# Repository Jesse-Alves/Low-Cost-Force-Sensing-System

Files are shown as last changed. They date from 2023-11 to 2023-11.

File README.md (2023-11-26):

<!-- Improved compatibility of back to top link: See: https://github.com/othneildrew/Best-README-Template/pull/73 -->

<!--
*** Thanks for checking out the Best-README-Template. If you have a suggestion
*** that would make this better, please fork the repo and create a pull request
*** or simply open an issue with the tag "enhancement".
*** Don't forget to give the project a star!
*** Thanks again! Now go create something AMAZING! :D
-->

<!-- PROJECT SHIELDS -->
<!--
*** I'm using markdown "reference style" links for readability.
*** Reference links are enclosed in brackets [ ] instead of parentheses ( ).
*** See the bottom of this document for the declaration of the reference variables
*** for contributors-url, forks-url, etc. This is an optional, concise syntax you may use.
*** https://www.markdownguide.org/basic-syntax/#reference-style-links
-->
[][linkedin-url]

<!-- PROJECT LOGO -->
<br />
<div align="center">
  <a href="https://healthtech.unistra.fr/">
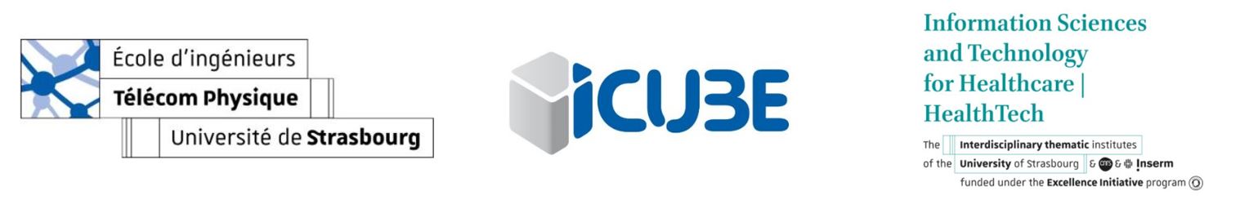
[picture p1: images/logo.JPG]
    
  </a>

  <h1 align="center">Low-Cost Force Sensing System Prototyping for Upper-Limb Rehabilitation</h1>

  <p align="center">
    <a href="https://github.com/Jesse-Alves?tab=repositories"><strong>View all repositories  »</strong></a>
    <br />
    <br />
  </p>
</div>

<!-- TABLE OF CONTENTS -->
<details>
  <summary>Table of Contents</summary>
  <ol>
    <li>
      <a href="#about-the-project">About The Project</a>
      <ul>
        <li><a href="#built-with">Built With</a></li>
      </ul>
    </li>
    <li>
      <a href="#getting-started">Getting Started</a>
      <ul>
        <li><a href="#prerequisites">Prerequisites</a></li>
<!--         <li><a href="#installation">Installation</a></li> -->
      </ul>
    </li>
    <li><a href="#usage">Usage</a></li>
<!--     <li><a href="#roadmap">Roadmap</a></li>
    <li><a href="#contributing">Contributing</a></li>
    <li><a href="#license">License</a></li> -->
    <li><a href="#contact">Contact</a></li>
<!--     <li><a href="#acknowledgments">Acknowledgments</a></li> -->
  </ol>
</details>

<!-- ABOUT THE PROJECT -->
## About The Project

Currently, robotics-assisted devices, such as exoskeleton and collaborative robotic arms, have been used for rehabilitation therapy. Where one of the biggest causes of the physical disability is stroke. However, despite the high benefits and potential of using these devices, the clinical application remains limited due mainly to the complexity and the high cost. Therefore, different strategies are used to overcome these limitations, such as the use of alternatives sensors and materials. In this context, this article presents the prototyping of a low cost and compact bracelet to detect the upper arm contraction using Force Sensing Resistor (FSR) and then, send the data from a cheap microcontroller to Robot Operating System (ROS2) environment.

Keywords: Rehabilitation, Post-Stroke, Robotic, FSR, Low-Cost.

[(Full article)](https://github.com/Jesse-Alves/Low-Cost-Force-Sensing-System-Prototyping-for-Upper-Limb-Rehabilitation/blob/main/Low-Cost%20Force%20Sensing%20System%20Prototyping%20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)

## Experiment with prototype

<div align="center">
    color picker
</div>

[(Full Test Video)](https://1drv.ms/v/s!Ah6ATMOdK-3mgutUfqPUrB_IlDdTVw?e=WdsoXN)

### Prototype Pictures

<div align="center">
  <a href=" ">
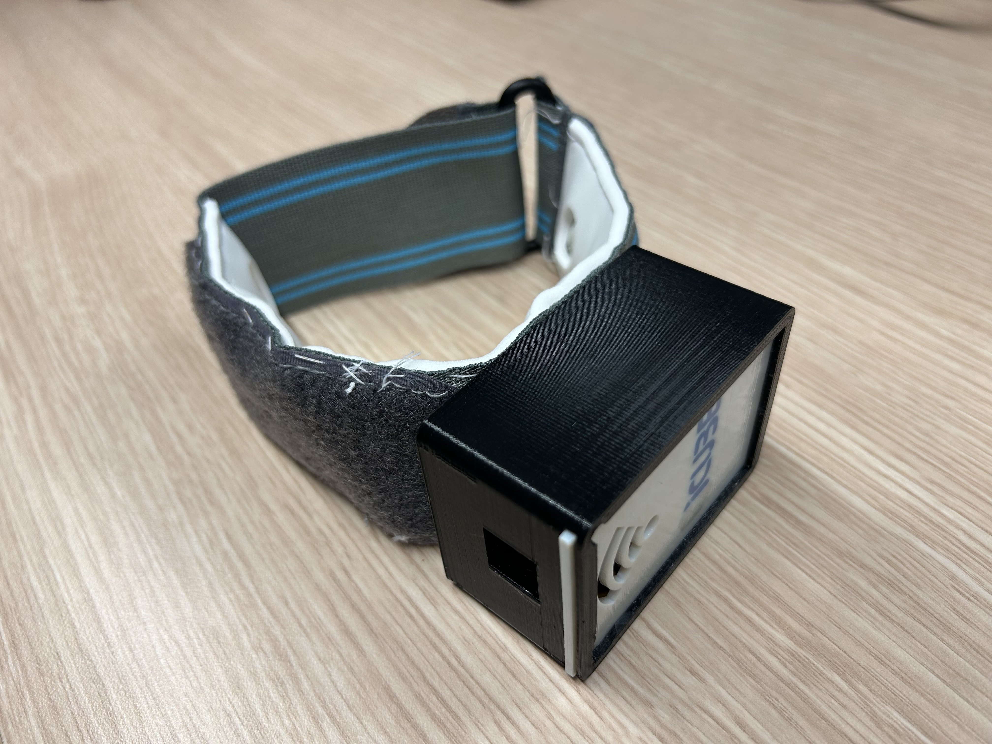
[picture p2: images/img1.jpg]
    
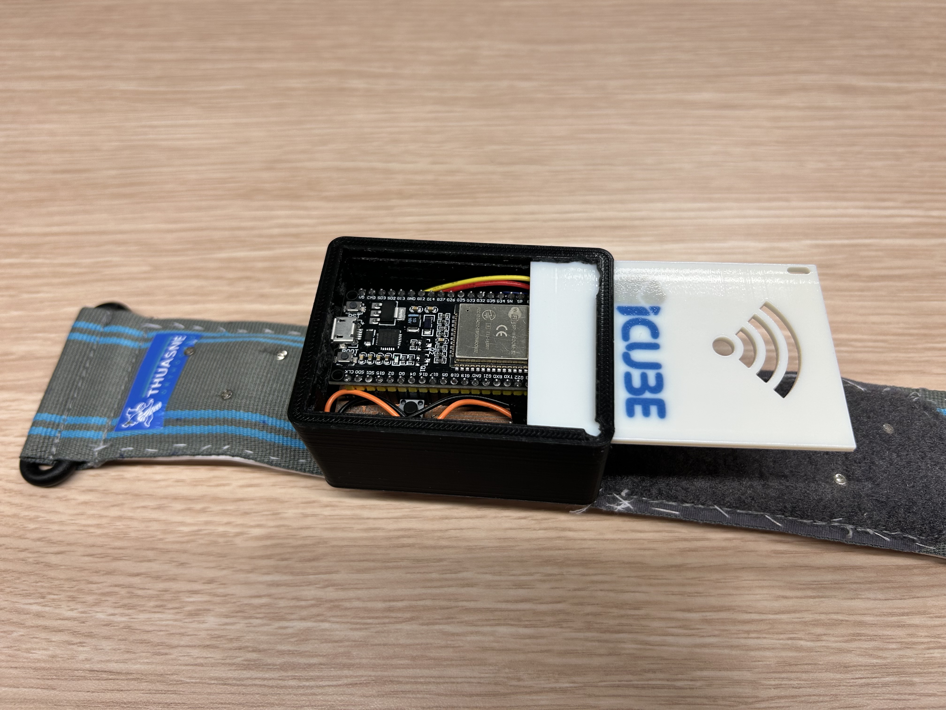
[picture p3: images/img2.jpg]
    
  </a>
</div>

<div align="center">
  <a href=" ">
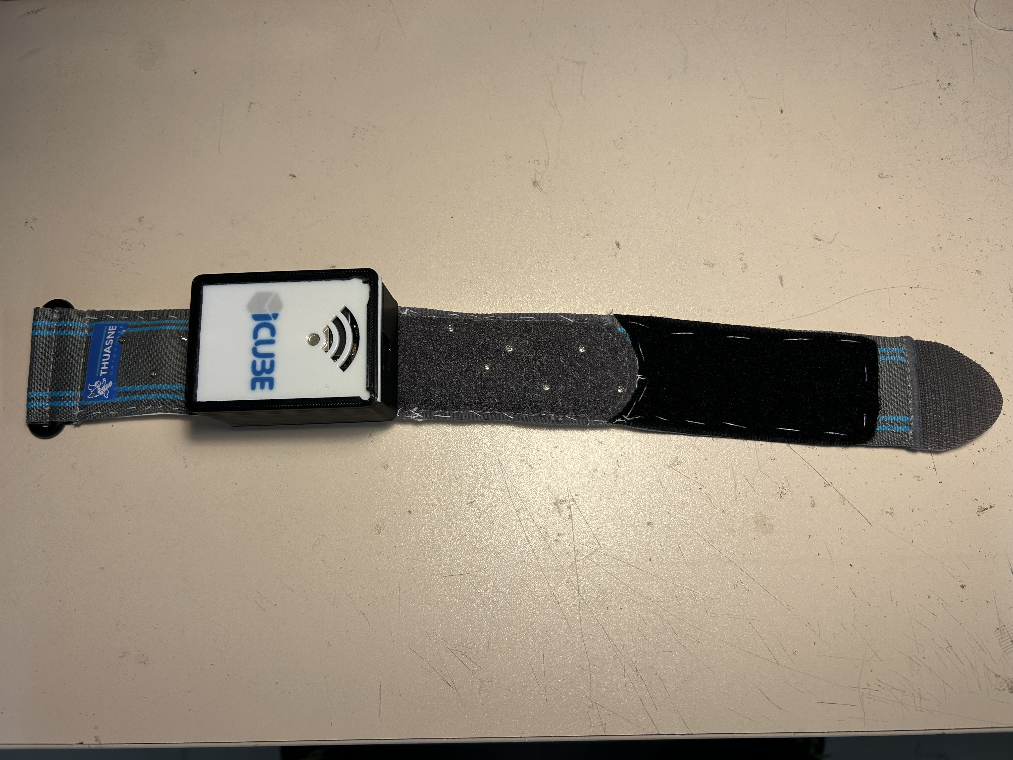
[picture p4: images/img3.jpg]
    
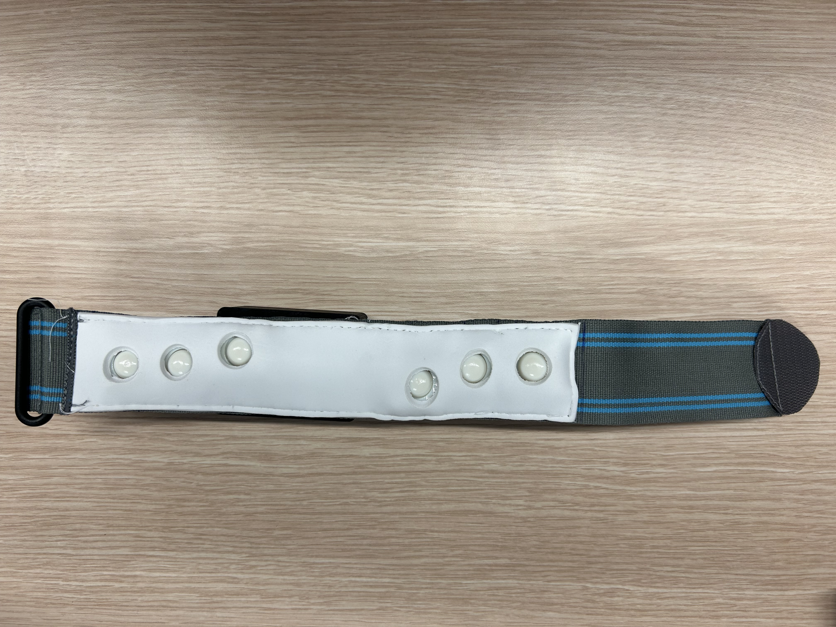
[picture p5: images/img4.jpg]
    
  </a>
</div>

<p align="right">(<a href="#readme-top">back to top</a>)</p>

### Built With
*  
*  
* 
* 
* 
* 
* 
* 
* 

<p align="right">(<a href="#readme-top">back to top</a>)</p>

<!-- GETTING STARTED -->
## Getting Started

This is medical device prototyping designed using microcontrollers, PCB manufacturing, CAD models and ROS2 environment.

### Prerequisites

All this project was built in ROS2 Humble environment, using ROS2 Control, ESP32 microcontroller, Arduino IDE and CREO PTC CAD software.

<!-- USAGE EXAMPLES -->
## Usage

All the codes and CAD designs of the project are available in the repository.

The written [Article](https://github.com/Jesse-Alves/Low-Cost-Force-Sensing-System-Prototyping-for-Upper-Limb-Rehabilitation/blob/main/Low-Cost%20Force%20Sensing%20System%20Prototyping%20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) has two appendices, one explains step by step how to reproduce the prototype and the second how to use the device.

<p align="right">(<a href="#readme-top">back to top</a>)</p>

<!-- CONTACT -->
## Contact

Jessé de Oliveira Santana Alves - [Linkedin - jessealves11](https://linkedin.com/in/jessealves11) - jessalves2@gmail.com

<p align="right">(<a href="#readme-top">back to top</a>)</p>

<!-- MARKDOWN LINKS & IMAGES -->
[linkedin-shield]: https://img.shields.io/badge/-LinkedIn-black.svg?style=for-the-badge&logo=linkedin&colorB=555
[linkedin-url]: https://linkedin.com/in/jessealves11

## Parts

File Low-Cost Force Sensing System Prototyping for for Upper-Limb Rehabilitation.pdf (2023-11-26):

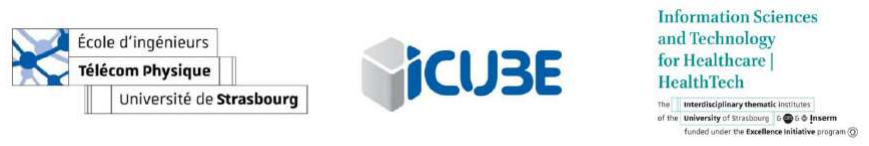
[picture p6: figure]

# Low-Cost Force Sensing System Prototyping for Upper-Limb Rehabilitation

### Jessé de Oliveira Santana Alves¹ Professor/Advisor: Maciej Bednarczyk and Bernard Bayle

1 Université de Strasbourg

### Abstract

Currently, robotics-assisted devices, such as exoskeleton and collaborative robotic arms, have been used for rehabilitation therapy. Where one of the biggest causes of the physical disability is stroke. However, despite the high benefits and potential of using these devices, the clinical application remains limited due mainly to the complexity and the high cost. Therefore, different strategies are used to overcome these limitations, such as the use of alternatives sensors and materials. In this context, this article presents the prototyping of a low cost and compact bracelet to detect the upper arm contraction using Force Sensing Resistor (FSR) and then, send the data from a cheap microcontroller to Robot Operating System (ROS2) environment.

Keywords: Rehabilitation, Post-Stroke, Robotic, FSR, Low-Cost.

### 1 Introduction

### 1.1 General Context

The stroke is defined by the World Stroke Organization as the interruption of the blood supply to part of the brain (Martins 2023) and is one of the main diseases responsible for long-term physical disability in adults (Azhar 2022). This interruption can cause different damages depending on which part of the brain is affected and how quickly it is treated. One of the most common damages are the lost of motor mobility and speech.
The Hemiparesis, defined as the weakness or the inability to move on one side of the body, is a common stroke consequence that causes difficulty in completing everyday tasks, such as the coordination, fine motor skills and movement precision. These motor system damages are directly related with changes in muscles architecture and the shortening of muscle fiber length, generating, in this way, less force and precision by the members of the human body.

Corresponding author(s): Jessé de Oliveira Santana Alves, Université de Strasbourg, jesse.alves@etu.unistra.fr

1

2 | Bracelet Prototyping
| In this context, the post-stroke rehabilitation is usually done with a combination of
physical and occupational therapy, being advised by the National Clinical Guideline for at least 45 minutes of physical therapy daily (Physiopedia 2022). These activities going from treadmill and exercises aimed at muscle strengthening to the use of high technology, such as virtual reality, electrical stimulation and robotic rehabilitation. This last one is a research trend in the field, where the robotic assistance can be used actively, passively and with haptic feedback. In (Lee 2020) these robots are classified in two main groups, the end effector model and exoskeleton. The last one is attached to the patient at multiple points, in order to match both join axes, the patient and the robot.

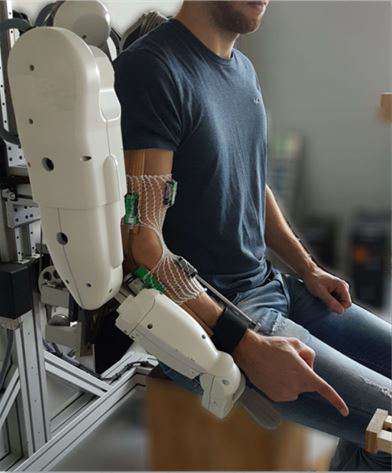
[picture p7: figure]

Figure 1: Exoskeleton Robot by (Saclay 2018).
The Figure 1 shows this configuration applied to the shoulder, upper-arm and forearm. In the present project this robot architecture is used, together with sensors to detect the muscle contraction from the patient, or at least its intention, and then, perform the physical therapy exercises and/or the day-to-day activities, such as grab objects and picking and place, giving them assistance while maintaining their autonomy (Azhar 2022).
Regarding the use of devices to detect the muscle contraction - object of contribution from this internship - different technologies can be used to measure the muscle activity, such as the surface electromyography (sEMG), inertial measurement unit (IMU), pressure sensors, force sensing resistors (FSR), electroencephalography and strain transducers. Among them, the electromyography (EMG) - considered the gold-standard technique used for the evaluation of muscle activity and contraction (Casaccia et al. 2015) - is the most common technology in the robotic application, due to the high number of important parameters present in the signal acquired. Because of this, it is possible to find important contributions in this field, such as the control for a hand exoskeleton rehabilitation (Wege & Zimmermann 2007; Mulas

Jessé Alves | 3

et al. 2005), the lower-extremity exoskeleton with one actuated degree of freedom in the knee joint (Fleischer et al. 2006), etc.
However, the EMG sensors are expensive and not easily available for individuals (Bawa & Banitsas 2022), being more used in rehabilitation clinics with specialized professionals, requiring a high cost for patients and medical insurances. For these reasons, there are also research branches in this field to seek, test and develop low-cost alternative sensors and devices that offer adequate performance for rehabilitation robot applications. Both for design low-Cost EMG Sensor compared to a commercial-based system (Bawa & Banitsas 2022; Prakash & Sharma 2021; Toro et al. 2019) and alternative low-cost sensors such as Force-Sensing Resistors (FSR) (Prakash et al. 2020; Castellini & Ravindra 2014).

### 1.2 The Research Goal

In this way, the present research aims to project a parsimonious device, both exoskeleton robot and muscle contraction measuring device, for upper-limb rehabilitation and force and precision compensator, similar to that shown in Figure 1. For that, low-cost materials are intended to be used in each part of the device. Therefore, it is necessary to prove scientifically that each parsimonious device part have a sufficient performance for these applications. Thus, regarding the muscle contraction measuring device, a cheap bracelet using FSR sensors was chosen to be tested and compared with EMG data and FSR commercial device, by Delsys brand.

### 1.2.1 The working principle of Force Sensing Resistors (FSR)

EMG sensors utilize electrodes to detect the electrical signals transmitted from the nerves to the muscles, thereby detecting muscle contractions. On the other hand, FSR sensors act as variable resistors that modify their resistance in response to applied force, being, in that way, easier to treat the voltage signal mapped between a range of resistance. The Force Sensing Resistors (FSR) used in this project are of the Shunt Mode type (Figure 2), where there are three layers, the top layer, called active area, is printed with conductive silver arranged into sets of interdigitating fingers, two sets, but not connected directly. The bottom layer, called conductive film, is a PET film made with a conductor material, usually carbon. Then, the middle layer, is an adhesive nonconductive spacer film that isolate the top layer from the bottom layer. Therefore, in this architecture, the unload state of the sensor can be interpreted as a infinitive resistor (in practice more than 10 MΩ), and when a force is applied, the semi conductive traces of top layer shunts the traces on bottom layer reducing the resistance until 1 kΩ or 1Ω, depending on the manufacturer.

(a) The layers | (b) The sensor

Figure 2: The FSR sensor Shunt Mode (Tekscan 2023).

### 1.3 The Research State of the Art

In (Azhar 2022), some initial experiments were made, showing that, within your limitations, it is possible to map the biceps contraction using FSR sensors inside a closed bracelet (Figure 3), through the variations of volumetric and stiffness of the muscle which exert radial pressure. Among these limitations and constraints, it is possible to highlight:
- The static drift - a phenomenon where the output sensor reading changes over time without any input modifications - of 21.4% for interlink brand and 6.2% for FlexiForce brand, after a constant load application during 20 hours observed in (Dabling et al. 2012) study.
- The non-linearity relationship between low force applied (range of 0-4N) and the voltage level (Sadun et al. 2016).
- The uncertain and unreliable results using the FSR sensors directly on the skin, thus demanding the use of some adapter between the sensor and the skin, where one type of adapter was originally designed for this application in this internship.
- And finally, the necessity to calibrate each sensor when these are used inside a closed bracelet, since the minimum and maximum value read on the FSR sensor will depend on the force used in the manual fixation of the bracelet on the upper-arm. This internship work will also present, as part of the prototyping, an efficient and intuitive way to calibrate these sensors.

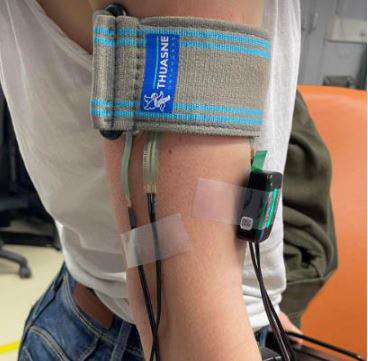
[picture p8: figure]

Figure 3: The FSR bracelet used in Azhar experiments (Adapted from Azhar (2022)).

### 1.4 The Present Internship Objectives and Specifications

In that context, the present internship aims to build a low-cost and compact prototype of a bracelet - the structure part, the hardware and the software - using FSR sensors and a microcontroller to detect the upper-arm contraction and send this information to ROS2 Environment. This prototype should take into account all the limitations described in the subsection 1.3 and be intuitive to manipulate for the user, since its goal is to accomplish the same and similar experiment describe in (Azhar 2022), replacing the setup shown in the Figure 3, in order to prove - with more accuracy -that a cheap bracelet has a sufficient performance to control the exoskeleton robot.

### 1.5 Work Environment

To achieve this task, the prototyping was made using both laboratories from Icube at Institute Surgery Guided Par L’image (IHU) (https://www.ihu-strasbourg.eu/) and from École d’Ingénieurs Télécom Physique (https://www.telecom-physique.fr/) Université de Strabourg. Where the main research team involved in the internship was the Robotics, Data science and Healthcare technologies (RDH) team. (https://rdh.icube.unistra.fr/index.php/Members) As supervisors, the professor Maciej Bednarczyk and professor Bernard Bayle guided and followed the entire prototyping process of the internship.

### 1.6 The Internship Management

In order to project, build and test the prototype during 8 weeks of internship, the work has been managed following the Japanese Kanban (https://www.youtube.com/watch?v=vU1Qp3dwnQs&t=7s) workflow management method, where all the tasks to accomplish the project are divided and subdivided in cards and dynamically categorized as Backlog, To Do, Doing, Pending and Done. This method was learned in the Digital Economics core taught in the HealthTech Master M1 program and applied using the Trello tool (Figure 4).

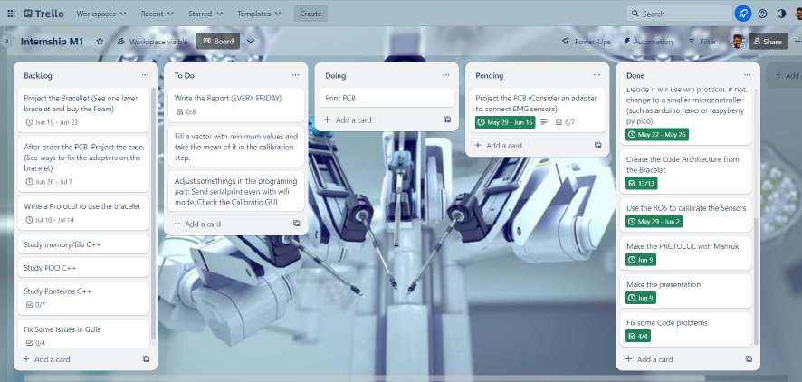
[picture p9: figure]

Figure 4: The Kanban used in Trello.

In that way, it was defined deadline for each macro task, as it is shown in the Table 1 below. It is also important to mention that this present report has been written during the prototyping process.

Table 1: The Macro Project Schedule
Tasks | Period
Write the code for the microcontroller, the Graphical Interface and ROS2 environment. | From 22/05/2023 until 06/06/2023
Project the printed circuit board (PCB) and select com-ponents from RS website. | From 06/06/2023 until 16/06/2023
Project the cases and test the circuits. | From 16/06/2023 until 23/06/2023
Mount all the parts on bracelet and test the prototype. | From 23/05/2023 until 15/06/2023

### 2 The Bracelet Prototyping

This section will present the methodology used to project, build and test the bracelet prototype. Therefore, it will be presented the methods used to validate each part of the device: the software, the hardware and the physical part. However, this report also presents a tutorial section to explain step by step how to reproduce the prototype in the Appendix A, more objectively and directly. Furthermore, it is presented in Appendix B an intuitive tutorial on how to use the prototype, once it is built.
The bracelet projected here is composed of three main parts, the box (Figure 5(a)), the sensors (Figure 5(b)) and the band (Figure 5(c)). The box is composed by a 3D printed case with the hardware part inside, the sensors are composed by the Force Sensing Resistors (FSR) inside the 3D printed adapters and the band is the tissue part responsible to attach on the upper-arm and gather all the other parts. As a final product, it is expected to reach a compacter version and with more features of the first prototype developed previously (Figure 6).
(a) The box. | (b) The sensors | (c) The sensors

Figure 5: The parts of the Bracelet Prototype.

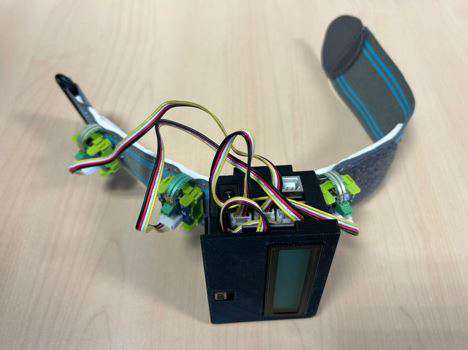
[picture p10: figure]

Figure 6: The first prototype.

Therefore, the process to build the new bracelet was:

1. Program and test the reading of the FSR sensors using the ESP32 (https://www.espressif.com/en/products/socs/esp32) microcontroller.
2. Program the sending from ESP32 and receiving in a python code the sensor reading via Serial and via Wi-Fi.
3. Program a Graphical Interface to choose and save the type of communication.
4. Program the Calibration Process.
5. Stream the reading data via ROS2
6. Read this topic (Subscribe Node) and make a 2DOF planar robot mimic the arm contraction.
7. Project the PCB.
8. Test each part of the circuit separately.
9. Project the sensor adapters.
10. Project the 3D printed cases.
11. Fix all the parts on the bracelet and test.

All these steps will be detailed in the following subsections.

### 2.1 The Software

The first part developed in this project was the software, starting for the microcontroller code, where the Groove Kit (https://wiki.seeedstudio.com/Grove-Round_Force_Sensor_FSR402/) was used to test the analogical reading by the ESP32 (Figure 7(a)) together with the Arduino IDE. This board has a 12-bit analogto-digital converter (ADC) for its analog input ports, thus, when the voltage level from the sensor varies between 0V and 3.3V, the number of discrete levels has 2

12 or 4096
distinct levels. Once this part was validated, the sensor data was programmed to be sent via serial from the ESP32 and be read in a python code. The same process was developed via Wi-Fi. Then, in order to be intuitive and practical the use prototype, a graphical user interface (GUI) in pyhton code, using the customtkinter library was projected to decide and save the type of communication (Figure 7(b)). In that way, the user needs to run this setup only the first time you configure the prototype, since this process saves these settings in the microcontroller.

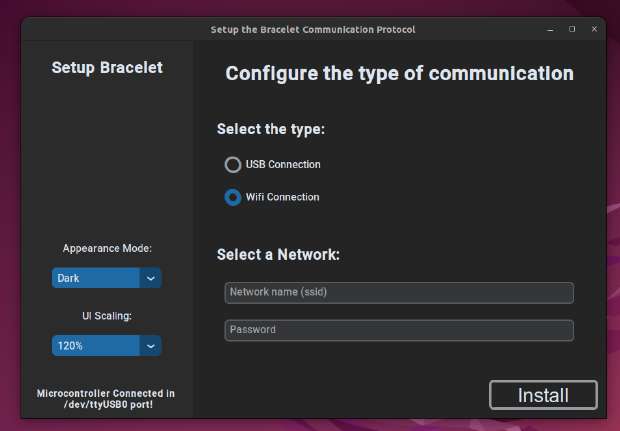
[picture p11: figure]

(a) The sensor reading test. | (b) The Type of Communication Setup GUI.

Figure 7: The software part.

### 2.1.1 The Calibration Process

Once both type of communication, serial and Wi-Fi, were validated, a calibrated process was developed to map the sensor reading between 0% of contraction and 100% of contraction. This procedure was projected to work as follows:

1. Fix the bracelet on the upper-arm.
2. Relax the arm, putting in a vertical position.
3. Get the minimum value read from each sensor. This process is done, filling a vector with the sensor data for each FSR during a custom time defined (such as 5 seconds or 10 seconds). Then, take the average of each vector and assign each vector separately its minimum value.
4. Now, contract the arm as much as possible and keep this position during the same time defined. The same process is used to get the maximum value.
5. Once these two steps is done, each sensor has its value mapped in terms of percentage between the average of the minimum value read and the maximum, following this expression:

F SRmapped =

F SRread − min
max − min
× 100% | (1)
6. Lastly, the FSR data sent is the average of all sensors attached on the bracelet, being possible to choose between 3 or 6 sensors.

All these process is also guided from an intuitive and objective way for a Graphical User Interface (GUI) written in python (Figure 8) in order to facilitate the use of the bracelet.

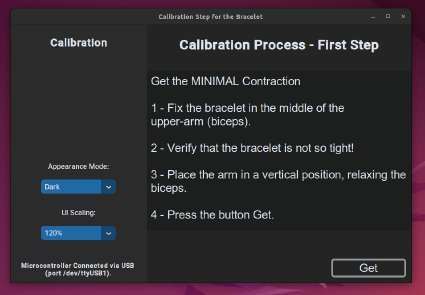
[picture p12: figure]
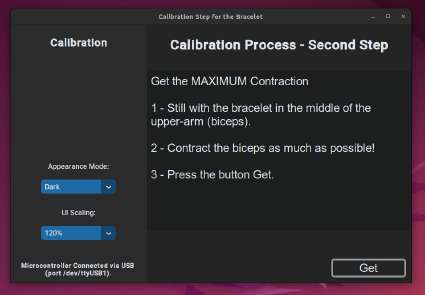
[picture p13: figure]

(a) Get Minimum Value. | (b) Get Maximum Value.

Figure 8: Calibration process GUI.

### 2.1.2 The ROS2 streaming data

Finally, the FSR data mapped received in a python code is published as a topic in ROS2 environment (Figure 9(a)) with until 1500 Hz stable publishing via USB port. And, in order to test the quality and performance of the signal streamed in ROS2 environment, it was used a 2DOF planar robot to mimic the arm contraction (Figure 9(b)).


(a) The FSR topic published in Plot Juggler. (b) The 2DOF planar robot.

Figure 9: The ROS2 environment.

### 2.2 The Printed Circuit Board (PCB)

Upon completing the software part, a Printed Circuit Board (PCB) was designed (Figure 11 and 12) and developed (Figure 10) to assembly the microcontroller, the sensor connectors, the resistors and capacitors to read and filter each sensor, a battery charger modulus to operate wireless, a power switch, a tension regulator for 3.3V and a push button to change the type of communication, such as change the WiFi SSID or password, change from WiFi to USB serial, etc.

Figure 10: The PCB manufacturing at TPS (https://www.telecom-physique.fr/) lab.


(a) The PCB layout. | (b) The PCB 3D visualization.

Figure 11: The PCB project.

Figure 12: The PCB electrical circuit.

### 2.3 The Sensor Adapters

The CAD model of an adapter was projected (Figure 13(a) and 13(b)) to allow the correct contact between the FSR sensors and the skin (Figure 5(b)) and at the same time fix the sensors on the bracelet (Figure 14). The spherical part of the sensor


increase the pressure on the arm skin, allowing the sensor to read with more precision the increase in muscle volume and stiffness. At the same time, the case keeps the sensor inside a flat surface, fixing and protecting it. Once the sensors were fixed on the bracelet with the adapters, the electrical connection with the PCB was made via custom wires (Figure 15), also built as part of the internship work, between the two bracelet layers (Figure 14).

(a) The CAD project. | (b) The Adapters Printed.

Figure 13: FSR Adapters.

Figure 14: The Sensors with Adapters fixed on bracelet.

Figure 15: The FSR wires.

### 2.4 The Circuit Case

A 3D printed case with a sliding lid also was projected on CREO PTC software to hold and fix the PCB and wires on the bracelet (Figure 16).


(a) The base | (b) The base
(c) The base | (d) The Lid.

Figure 16: The Case.

### 2.5 The Battery Case

Finally, since the bracelet was projected to be used with a lithium battery, a battery case, shown in the Figure 17, also was projected to hold the battery and fix it on the bracelet.


(a) (b)


(c) (d)

Figure 17: The battery case.

### 3 Results

### 3.1 Preliminary Tests and Results

### 3.1.1 The Hardware

Before to test the entire bracelet, partial tests were performed. Thus, regarding the PCB, the circuit projected was tested via numerical simulation in Proteus software, then was tested each part separately on a breadboard, in order to validate on the practices the circuit projected. Therefore, the voltage level of each sensor was tested (Figure 18) and retested at this point (Figure 14) in the prototyping, as well as the battery charging circuit (Figure 19). Once these steps were validated, the PCB soldering started.


Figure 18: The voltage test of each sensor.

(a) The CAD project. | (b) The Adapters Printed.

Figure 19: FSR Adapters.

### 3.1.2 The Software

The same preliminary test was done in order to validate the software. Thus, the data sent from the bracelet was recorded in the ROS2 environment and compared with the FSR commercial sensors, by Delsys brand. The test protocol followed was similar to that performed in (Azhar 2022). Where the data average of three sensors connected to the bracelet prototype was compared with the data average of three sensors connected to the Delsys device (Figure 20). The experiment first followed the calibration process described in section 2.1.1, then perform three slow and three fast contractions holding a 1 kg weight in a 45 seconds interval. The test was repeated with a 2 kg weight. The percentage of contractions for 1kg in terms of time is shown in the (Figures 21 and 22).


(a) The Prototype and Delsys device on the arm.
(b) The experiment setup.

Figure 20: The Experimental Test to validate the bracelet software.


Figure 21: The 1 kg test.


Figure 22: The 2 kg test.

### 3.2 The Final Prototype

After the preliminary tests and validations, the bracelet was mounted (Figure 23). The box is positioned on the external layer (Figure 24(a)), while the sensors - fixed between the layers with the adapters - have the spherical, responsible for the contact with the skin, part on the internal layer (Figure 24(b)). The case was projected with a sliding lid (Figure 25) and the band was adapted in order to increase its size, to fit in arms with larger circumferences (Figure 26). The battery case was printed but it was not fixed on the bracelet, the reason is explained in the discussion section. A video showing the working of the bracelet prototype is available at the link: The Bracelet Operation. (https://1drv.ms/v/s!Ah6ATMOdK-3mgutUfqPUrB_IlDdTVw?e=Dn0MQK)


Figure 23: The bracelet closed.


(a) The front of the bracelet. | (b) The back of the bracelet.

Figure 24: The Bracelet opened.

(a) (b)

Figure 25: The Bracelet Box.

(a) Original. | (b) Size Increased.

Figure 26: The Bracelet Size Adaption.

### 4 Discussion

A bracelet prototype was projected, developed and tested during this present internship. Thus, this section will describe and discuss some limitations, challenging and advantages of the final device and of the internship itself. The most limiting and challenging factor of this stage was certainly the time, where project, develop and test a new prototype in 8 weeks caused some unsolved problems. For instance, the printed PCB that was delivered has a short clearance between the pads and the traces. This caused a great deal of difficulty in the process of soldering the board, in addition to causing a short circuit that burned the battery charging traces on the PCB. For this reason, the prototype delivered does not have the battery case attached to the band. Another perceived problem in the mounting process was the position of the sensor connectors associated with the box case size, not allowing the circuit to enter inside the designed case, which had to be modified with a Dremel micro-grinder. This problem should be solved with both upgraded box CAD and PCB project delivered, however, for time reason, this new PCB and the box was not printed. Regarding the band, the short width caused problems to fix the sensors between the two layers, in addition to reduce the flexibility of the bracelet after the sewing (Figure 14). For this reason, it is highly recommended to use a wider custom band, where the sensor adapters can be positioned side by side with a high distance between each pair, as it is shown in the Figure 27(a). Finally, concerning the software, the calibration process was updated in the last internship week, because the first version worked getting a unique value read by each sensor and set as the min and max. Now, the calibration process considers the min and max of the data average during a defined time. After this software upgrade, the Wi-Fi communication is not working correctly, thus, it is necessary to debug this part of the code.

Despite these problems, even the prototype delivered presented good advantages, in terms of price, since it was built with cheap materials, but also in terms of performance. Since the device is compact, suitable for different users, intuitive to perform, well conditioned and tested. The sensor adapters projected solved different problems concerning the limitation of the FSR sensors, such as its fragility when folding, the contact with the skin, providing the correct reading and its firmness in the band fixing. In addition, concerning to the software, the prototype was capable to streaming via USB with stability the data in ROS2 environment with until 1500 Hz, what is more than enough to its application (probably 500 Hz). The prototype also was projected to work wireless, increasing the bracelet mobility. Finally, the simple and intuitive graphical interface for the calibration process here developed also solved the offset problem caused when FSR sensors are fixed on a closed bracelet. Since both minimum and maximum sensor value will depend on how much the user will tighten the bracelet on the arm initially. Thus, this procedure will map the contraction between these two read value. Thereby, the delivered prototype is ready to perform tests with Commercial devices, in order to compare, understanding better the limitations itself and probably proof with different experiments that a cheap bracelet has a sufficient performance for this application.

### 5 Conclusion

Despite all the limitations described in the discussion section, for a internship of 8 weeks, the prototype developed has good features and preliminary results, having in this way a high potential to be used in this application. Thereby, it is necessary to perform test comparing with validated commercial devices and also directly with robots.

### 6 Perspectives

For future work, it is possible to upgrade the prototype developed and perform more accurate experiments. Starting for the upgrades, as it was already mentioned, a wider bracelet is recommended for the next prototype (Figure 27(a)), increasing the flexibility of the bracelet.

(a) Recommended sensor layout. | (b) Delsys connector.

Figure 27
In addition, it is also possible to project a compacter version of the PCB presented in this work, where Surface-Mount Devices (https://en.wikipedia.org/wiki/Surface-mount_technology) (SMDs) can be used to save space on the board together with smaller connectors for the sensors. Finally, depending on how the bracelet will be fixed on the exoskeleton, the device can use the robot power source energy, reducing more the PCB size.

### 6.1 More accurate experiments

Regarding the experiments, it is possible to test the bracelet with a real exoskeleton, performing the rehabilitation tasks in order to evaluate the prototype performance in the practices. Despite this, it is also possible to compare the prototype and the Delsys devices in two different ways: asynchronously and synchronously.
1. The first one can be done recording the prototype data following the experimental protocol presented in (Azhar 2022), then unplugging the sensor connector from the PCB and plug in the Delsys adapter, (https://delsys.com/trigno-fsr/) in order to compare the same sensors without changes in the bracelet position. For this, it will be necessary to create a cable where one end is connected to this Molex (https://fr.rs-online.com/web/p/boitiers-de-connecteurs-pour-circuits-imprimes/2332775) and the other connected to this Delsys male plug (Figure 27(b)).
2. The synchronous way is to reprogram the prototype to be trigger together with the Delsys device at the same time, where the bracelet will use three sensors and the Delsys the other three sensors. To do that, this device (https://delsys.com/trigger-module/) should be used.
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

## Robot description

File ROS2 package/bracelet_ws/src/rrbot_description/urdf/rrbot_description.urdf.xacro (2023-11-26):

<?xml version="1.0"?>
<robot xmlns:xacro="http://www.ros.org/wiki/xacro">

  <xacro:macro name="rrbot" params="parent *origin">

  <!-- Constants for robot dimensions -->
  <xacro:property name="mass" value="1" /> <!-- arbitrary value for mass -->
  <xacro:property name="width" value="0.1" /> <!-- Square dimensions (widthxwidth) of beams -->
  <xacro:property name="height1" value="2" /> <!-- Link 1 -->
  <xacro:property name="height2" value="0.5" /> <!-- Link 2 -->
  <xacro:property name="height3" value="0.6" /> <!-- Link 3 -->
  <xacro:property name="axel_offset" value="0.05" /> <!-- Space btw top of beam and the each joint -->
  
  <material name="orange">
     <color rgba="1 0.5 0 1"/>
  </material>
  
  <material name="yellow">
     <color rgba="1 1 0 1"/>
  </material>

  <material name="blue">
    <color rgba="0.0 0.0 0.8 1.0"/>
  </material>

  <joint name="base_joint" type="fixed">
    <xacro:insert_block name="origin" />
    <parent link="${parent}"/>
    <child link="base_link" />
  </joint>

  <!-- Base Link -->
  <link name="base_link">
    <collision>
      <origin xyz="0 ${height1/2} 0" rpy="0 0 0"/>
      <geometry>
        <box size="0.05 ${height1} 0.05"/>
      </geometry>
    </collision>

    <visual>
      <origin xyz="0 ${height1/2} 0" rpy="0 0 0"/>
      <geometry>
        <box size="${width} ${height1} ${width}"/>
      </geometry>
      <material name="blue"/>
    </visual>

    <inertial>
      <origin xyz="0 ${height1/2} 0" rpy="0 0 0"/>
      <mass value="${mass}"/>
      <inertia ixx="${mass / 12.0 * (width*width + height1*height1)}" ixy="0.0" ixz="0.0" izz="${mass / 12.0 * (height1*height1 + width*width)}" iyz="0.0" iyy="${mass / 12.0 * (width*width + width*width)}"/>
      </inertial>
    </link>

    <joint name="joint1" type="continuous">
      <parent link="base_link"/>
      <child link="link1"/>
      <origin xyz="0 ${height1 - axel_offset} ${width}" rpy="0 0 0"/>
      <axis xyz="0 0 1"/>
      <dynamics damping="0.7"/>
    </joint>

    <!-- Middle Link -->
    <link name="link1">
      <collision>
        <origin xyz="${height2/2 - axel_offset} 0 0" rpy="0 0 0"/>
        <geometry>
          <box size="${height2} ${width} ${width}"/>
        </geometry>
      </collision>

      <visual>
        <origin xyz="${height2/2 - axel_offset} 0 0" rpy="0 0 0"/>
        <geometry>
          <box size="${height2} ${width} ${width}"/>
        </geometry>
        <material name="yellow"/>
      </visual>

      <inertial>
        <origin xyz="${height2/2 - axel_offset} 0 0" rpy="0 0 0"/>
        <mass value="${mass}"/>
        <inertia izz="${mass / 12.0 * (width*width + height2*height2)}" ixy="0.0" ixz="0.0" iyy="${mass / 12.0 * (height2*height2 + width*width)}" iyz="0.0" ixx="${mass / 12.0 * (width*width + width*width)}"/>
        </inertial>
      </link>

      <joint name="joint2" type="continuous">
        <parent link="link1"/>
        <child link="link2"/>
        <origin xyz="${height2 - axel_offset*2} 0 ${width}" rpy="0 0 0"/>
        <axis xyz="0 0 1"/>
        <dynamics damping="0.7"/>
      </joint>

      <!-- Top Link -->
      <link name="link2">
        <collision>
          <origin xyz="${height3/2 - axel_offset} 0 0" rpy="0 0 0"/>
          <geometry>
            <box size="${height3} ${width} ${width}"/>
          </geometry>
        </collision>

        <visual>
          <origin xyz="${height3/2 - axel_offset} 0 0" rpy="0 0 0"/>
          <geometry>
            <box size="${height3} ${width} ${width}"/>
          </geometry>
          <material name="orange"/>
        </visual>

        <inertial>
          <origin xyz="${height3/2 - axel_offset} 0 0" rpy="0 0 0"/>
          <mass value="${mass}"/>
          <inertia izz="${mass / 12.0 * (width*width + height3*height3)}" ixy="0.0" ixz="0.0" iyy="${mass / 12.0 * (height3*height3 + width*width)}" iyz="0.0" ixx="${mass / 12.0 * (width*width + width*width)}"/>
          </inertial>
        </link>

        <joint name="tool_joint" type="fixed">
          <origin xyz="1 0 0" rpy="0 0 0" />
          <parent link="link2"/>
          <child link="tool_link" />
        </joint>

        <!-- Tool Link -->
        <link name="tool_link">
        </link>

  </xacro:macro>

</robot>

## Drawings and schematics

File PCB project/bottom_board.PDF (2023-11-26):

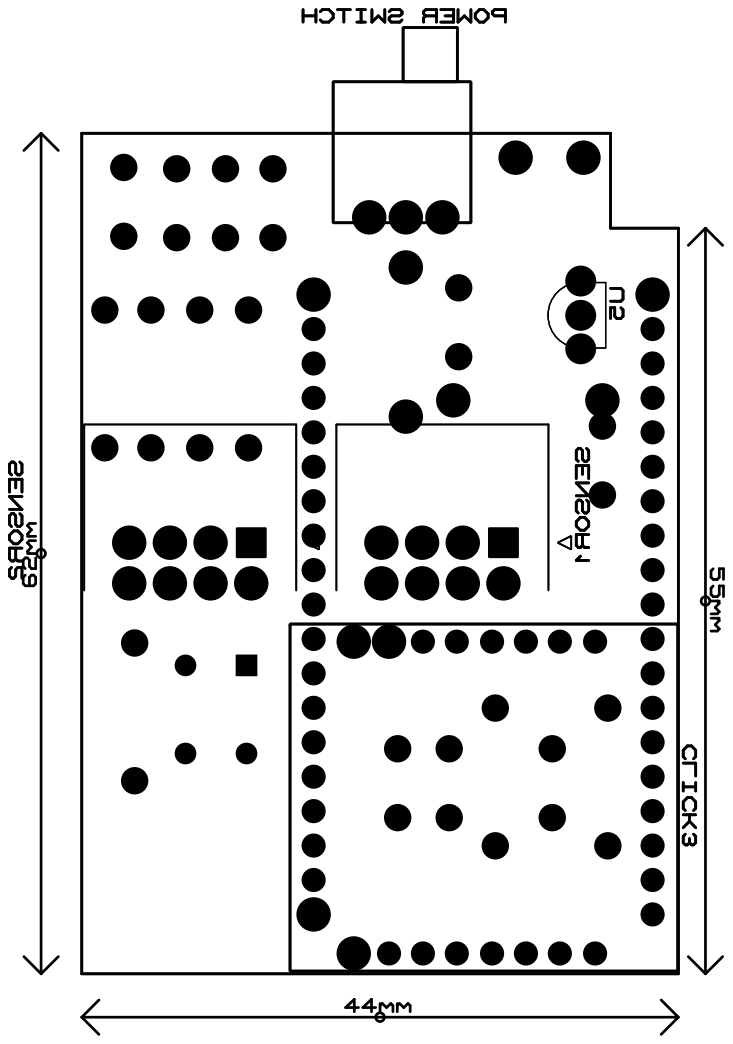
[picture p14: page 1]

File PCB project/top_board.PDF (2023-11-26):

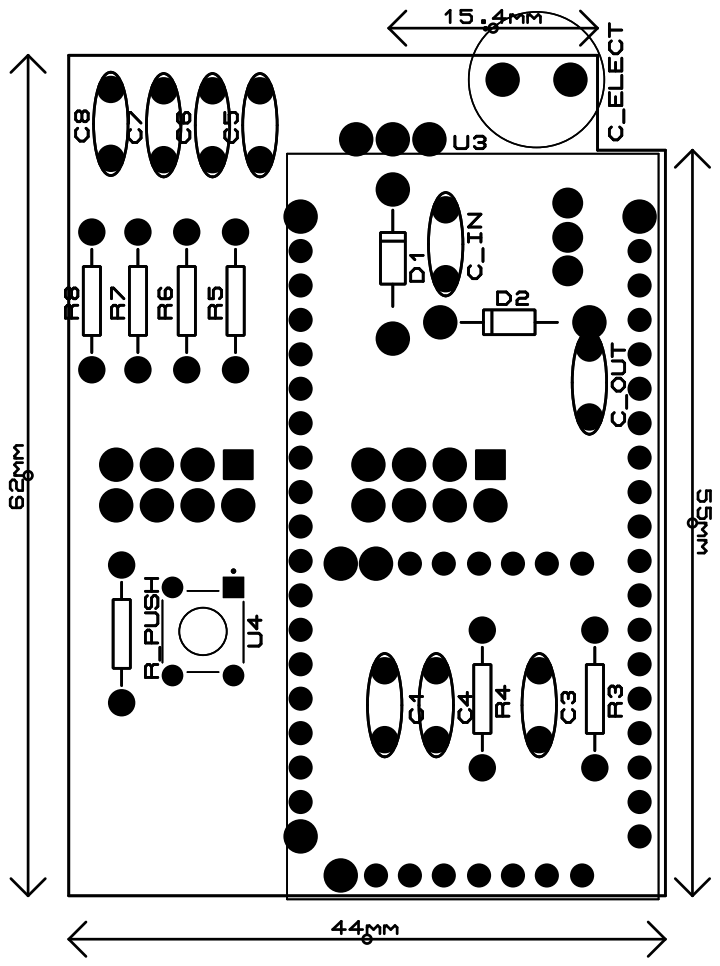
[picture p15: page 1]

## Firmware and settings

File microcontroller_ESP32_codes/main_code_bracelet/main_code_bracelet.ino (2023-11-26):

    /////////////////////////////////////////////////////////////////
   //        BRACELET TO MEASURE THE UPPER-ARM CONTRACTION        //
  //           Author: Jesse de Oliveira Santana Alves           //
 //                 Email: jessalves2@gmail.com                 //
/////////////////////////////////////////////////////////////////

// =======================================================
// ====================>  Libraries  <====================
// =======================================================
#include <FS.h>
#include <SPIFFS.h>
#include <ArduinoJson.h>

#include <WiFi.h>
#include <WiFiUdp.h>
#include <Arduino.h>
#include <iostream>
#include <stdio.h>
#include "AsyncUDP.h"

#include <vector>
#include <numeric>

// =======================================================
// ================>  Global Variables  <=================
// =======================================================

// ============================================ ADJUST VARIABLES ================================================

// Define the quantity of sensors - YOU JUST CAN CHOOSE 6 OR 3.
int qtd_sensors = 3;

// Define the time [IN SECONDS] desired for get minimum and maximum time in calibration.
int calibration_time = 5; //seconds

// The frequency to send data in microcontroller (Hz)
unsigned long timer_frequency = 2000; // Hz

// ==============================================================================================================

// =======> Sensor and Calibration
// The Sensors Inputs ports in ESP32 board
#define sensor1  25
#define sensor2  27
#define sensor3  32
#define sensor4  33
#define sensor5  34
#define sensor6  35
//#define sensor7  32
//#define sensor8  4

// The FSR variables for 6 or 3 sensors
float fsr1, fsr2, fsr3, fsr4, fsr5, fsr6, fsr;
float fsr1_min, fsr2_min, fsr3_min, fsr4_min, fsr5_min, fsr6_min;
float fsr1_max, fsr2_max, fsr3_max, fsr4_max, fsr5_max, fsr6_max;
float value, v_min, v_max, v_mapped;
unsigned long startTime; // Variable for calibration process

// =======> Reset Button - To call the protocol setup
#define buttonPin 15

// =======> Digital Outputs to Controll Battery Charging Current with Modulus Click3
#define sclPin 22
#define sdaPin 21


// =======> Wifi Communication
AsyncUDP udp;
String confirm_message;

// =======> Setup Communication
const char* type_protocol;
const char* ssid_json;
const char* password_json; 
StaticJsonDocument<200> doc;  // Create a JSON object
String tp_check;

// =======> GUI variables
String type_protocolGUI;
String ssidGUI;
String passwordGUI;
int cont = 0;


// =======> Timer Callback Variables
unsigned long previousTime = 0;
unsigned long interval = 1000/timer_frequency; // Time interval in milliseconds (1 second)
unsigned long currentTime;

// =======================================================
// ====================>  Functions  <====================
// =======================================================
void import_initial_variables(){
  // Initialize SPIFFS
  if (!SPIFFS.begin(true)) {
    Serial.println("An error occurred while mounting SPIFFS");
    return;
  }

  // Read the file from SPIFFS
  File file = SPIFFS.open("/protocol_info.json", "r");
  if (!file) {
    Serial.println("Failed to open file for reading");
    return;
  }

  // Parse the JSON file and store the data in the JSON object
  DeserializationError error = deserializeJson(doc, file);
  if (error) {
    Serial.println("Failed to parse file");
  }

  // ============================================= Reading the variables from json file
  type_protocol = doc["type_protocol"];
  ssid_json     = doc["ssid_json"];
  password_json = doc["password_json"]; 


  // Print Variable to test if the reading was with success
  // Serial.println("The values was imported with succes: ");
  // Serial.println(type_protocol);
  // Serial.println(ssid_json);
  // Serial.println(password_json);
  // Serial.println(" ");

  // Close the file
  file.close();
}
void save_variable_jsonfile(const char* variable, const char* new_value){

   // Initialize SPIFFS
  if (!SPIFFS.begin(true)) {
    Serial.println("An error occurred while mounting SPIFFS");
    return;
  }

  // ========================================= Update the specific variable
  doc[variable] = new_value;

  // Open the file in write mode
  File file = SPIFFS.open("/protocol_info.json", "w");
  if (!file) {
    Serial.println("Failed to open file for writing");
    return;
  }
  // Serialize the JSON object to the file
  if (serializeJson(doc, file) == 0) {
    Serial.println("Failed to write to file");
  }
  // Close the file
  file.close();  
}
void setup_type_of_communication(){  

  // ===============================> Get data from setup bracelet python executable
  Serial.println("Waiting the Setup GUI...");
  while(true){    
    //Serial.println(cont);

    if (Serial.available() > 0) {
      if (cont == 0){
        type_protocolGUI = Serial.readString();  // Read the incoming data from the serial port
        if ((type_protocolGUI == "serial") || (type_protocolGUI == "wifi")){
          cont++;
          Serial.println("received protocol: " + String(type_protocolGUI));  
        }
      }
      else if(cont == 1){
        ssidGUI = Serial.readString();  // Read the incoming data from the serial port
        cont++;
        Serial.println("received ssid: " + String(ssidGUI));          
      }
      else if(cont == 2){
        passwordGUI = Serial.readString();  // Read the incoming data from the serial port        
        Serial.println("received password: " + String(passwordGUI));          
        break;
      }
    }
  }

  //Serial.println("Passed the while loop: ");
  //type_protocolGUI = "wifi";
  //ssidGUI = "Jesse Alves";
  //passwordGUI = "thalitajesse";  
  //Serial.println(type_protocolGUI.c_str());
  //Serial.println(ssidGUI.c_str());
  //Serial.println(passwordGUI.c_str());

  // ===============================> Convert String to Const Char
  type_protocol = type_protocolGUI.c_str();
  ssid_json = ssidGUI.c_str();
  password_json = passwordGUI.c_str();

  // ===============================> Save receipt data in json file
  const char* tp_name = "type_protocol";
  const char* ssid_name = "ssid_json";
  const char* pass_name = "password_json";
  
  save_variable_jsonfile(tp_name, type_protocol);
  save_variable_jsonfile(ssid_name, ssid_json);
  save_variable_jsonfile(pass_name, password_json);

  delay(1000);
  // Configure wifi
  if (type_protocolGUI == "wifi"){
    configure_wifi();
  }
     
  // After that, the code go to Calibration Step (In Setup Function).
}
void configure_wifi(){
  import_initial_variables();

  WiFi.mode(WIFI_STA);
  WiFi.begin(ssid_json, password_json);
  if (WiFi.waitForConnectResult() != WL_CONNECTED) {
      Serial.println("WiFi Failed! Trying to connect again!");
      delay(1000);
      configure_wifi();
      //while(1) {
      //    delay(1000);
      //}
  }
  if(udp.listen(1234)) {
      Serial.print("Wifi Connected!! The UDP Listening on IP: ");
      Serial.println(WiFi.localIP());
      udp.onPacket([](AsyncUDPPacket packet) {
          // ======================================================> Get data from python/ROS code via Wifi
          char* tmpStr = (char*) malloc(packet.length() + 1);
          memcpy(tmpStr, packet.data(), packet.length());
          tmpStr[packet.length()] = '\0'; // ensure null termination
          confirm_message = String(tmpStr);
          free(tmpStr); // Strign(char*) creates a copy so we can delete our one

          //Serial.println(confirm_message);          
      });
  }

  // Notify that wifi connected
  // ========================> Turn on a green LED here
  
}
void getWifimsg(){
  if(udp.listen(1234)) {
      udp.onPacket([](AsyncUDPPacket packet) {
          // ======================================================> Get data from python/ROS code via Wifi
          char* tmpStr = (char*) malloc(packet.length() + 1);
          memcpy(tmpStr, packet.data(), packet.length());
          tmpStr[packet.length()] = '\0'; // ensure null termination

          // Get the Wifi Message from Python Code 
          confirm_message = String(tmpStr);
          //Serial.println(confirm_message);

          free(tmpStr); // Strign(char*) creates a copy so we can delete our one                    
      });
  }
}
void getSerialmsg(){
    if (Serial.available() > 0) {        
      confirm_message = Serial.readString();  // Read the incoming data from the serial port
    }  
}
void calibration(){
    // ======================================= Vectors for Calibration ===================================================
    float sum = 0.0;
    std::vector<float> vec_fsr1;    std::vector<float> vec_fsr2;    std::vector<float> vec_fsr3;
    std::vector<float> vec_fsr4;    std::vector<float> vec_fsr5;    std::vector<float> vec_fsr6;
    
 
    //================================================== WIFI =============================================================   
    if (tp_check == "wifi"){

      // I - Notify that the communication is via serial
      confirm_message = " ";
      //Serial.println("wifi");
      while(true){
        Serial.println("wifi");
        udp.broadcast("wifi");
        delay(10);
        getWifimsg();               
        if (confirm_message == "got_it"){
          //Serial.println("First Got it message received!"); 
          //Serial.println("got_it");  
          break;
        }        
        

        // =================================== Check if the setup button was pressed ===========================
        if((digitalRead(buttonPin))){
          type_protocol = "not configured";
          const char* tp_name = "type_protocol";  
          save_variable_jsonfile(tp_name, type_protocol);
          setup_type_of_communication();        
        } 
        // ======================================================================================================
      }    


      // II - Get the MINIMUM value of each FSR sensors
      // ===========================> Wait the confirmation in GUI to start the reading
      confirm_message = " ";
      while(true){      
        //Serial.println("getting_minimum");
        getWifimsg();
        if (confirm_message == "got_it"){   
          //Serial.println("Second Got it message received!"); 
          //delay(50);   
          //Serial.println("got_it"); 
          //udp.broadcast("got_it");   
          break;
        }   

        // =================================== Check if the setup button was pressed ===========================
        if((digitalRead(buttonPin))){
          type_protocol = "not configured";
          const char* tp_name = "type_protocol";  
          save_variable_jsonfile(tp_name, type_protocol);
          setup_type_of_communication();        
        } 
        // ======================================================================================================
      }

      // ===========================> Start to read during the calibration time defined
      startTime = millis();
      while (millis() - startTime < 1000*calibration_time) {  
        //udp.broadcast("calibrating...");
        //Serial.println("calibrating...");
        delay(10);        
        vec_fsr1.push_back(analogRead(sensor1));   vec_fsr2.push_back(analogRead(sensor2));   vec_fsr3.push_back(analogRead(sensor3));
        if (qtd_sensors == 6){
          vec_fsr4.push_back(analogRead(sensor4));   vec_fsr5.push_back(analogRead(sensor5));   vec_fsr6.push_back(analogRead(sensor6)); 
        }
      }

      // for (int ii=0;ii<50;ii++){
      //   udp.broadcast("Calibration finished");
      //   Serial.println("Calibration finished");
      // }  
      
      // Compute the Vector Mean
      sum = std::accumulate(vec_fsr1.begin(), vec_fsr1.end(), 0.0);      fsr1_min = sum / vec_fsr1.size();
      sum = std::accumulate(vec_fsr2.begin(), vec_fsr2.end(), 0.0);      fsr2_min = sum / vec_fsr2.size();
      sum = std::accumulate(vec_fsr3.begin(), vec_fsr3.end(), 0.0);      fsr3_min = sum / vec_fsr3.size();
      if (qtd_sensors == 6){
        sum = std::accumulate(vec_fsr4.begin(), vec_fsr4.end(), 0.0);      fsr4_min = sum / vec_fsr4.size();
        sum = std::accumulate(vec_fsr5.begin(), vec_fsr5.end(), 0.0);      fsr5_min = sum / vec_fsr5.size();
        sum = std::accumulate(vec_fsr6.begin(), vec_fsr6.end(), 0.0);      fsr6_min = sum / vec_fsr6.size();
      }
      
      //Serial.println("Clearing the vectors...");      
      // Clear the Vector to use them to maximum as well.
      vec_fsr1.clear();      vec_fsr2.clear();      vec_fsr3.clear();
      if (qtd_sensors == 6){vec_fsr4.clear();      vec_fsr5.clear();      vec_fsr6.clear();}
 
      
      //Serial.println("got_min");
      // for (int ii=0;ii<10;ii++){
      //   udp.broadcast("got_min");
      //   delay(10);
      // }
      udp.broadcast("got_min");
      udp.broadcast("got_min");
          
      // SEND AND RECEIVE CONFIRMATION.
      confirm_message = " ";
      while(true){     
        //getSerialmsg();
        getWifimsg();
        //delay(50);
        if (confirm_message == "got_it"){ 
          //Serial.println("First Got it message received!");   
          //delay(50); 
          //Serial.println("got_it");    
          //udp.broadcast("got_it"); 
          break;
        }       
      } 

      // III - Get the MAXIMUM value of each FSR sensors
      startTime = millis();
      while (millis() - startTime < 1000*calibration_time) {  
        //Serial.println("calibrating...");
        //udp.broadcast("calibrating...");
        delay(10); 
        vec_fsr1.push_back(analogRead(sensor1));   vec_fsr2.push_back(analogRead(sensor2));   vec_fsr3.push_back(analogRead(sensor3));
        if (qtd_sensors == 6){
          vec_fsr4.push_back(analogRead(sensor4));   vec_fsr5.push_back(analogRead(sensor5));   vec_fsr6.push_back(analogRead(sensor6));
        }
      }

      // for (int ii=0;ii<50;ii++){
      //   Serial.println("Calibration finished");
      //   udp.broadcast("Calibration finished");
      // }  

      // Compute the Vector Mean
      sum = std::accumulate(vec_fsr1.begin(), vec_fsr1.end(), 0.0);      fsr1_max = sum / vec_fsr1.size();
      sum = std::accumulate(vec_fsr2.begin(), vec_fsr2.end(), 0.0);      fsr2_max = sum / vec_fsr2.size();
      sum = std::accumulate(vec_fsr3.begin(), vec_fsr3.end(), 0.0);      fsr3_max = sum / vec_fsr3.size();
      if (qtd_sensors == 6){
        sum = std::accumulate(vec_fsr4.begin(), vec_fsr4.end(), 0.0);      fsr4_max = sum / vec_fsr4.size();
        sum = std::accumulate(vec_fsr5.begin(), vec_fsr5.end(), 0.0);      fsr5_max = sum / vec_fsr5.size();
        sum = std::accumulate(vec_fsr6.begin(), vec_fsr6.end(), 0.0);      fsr6_max = sum / vec_fsr6.size();
      }

      // Clear the Vectors
      vec_fsr1.clear();      vec_fsr2.clear();      vec_fsr3.clear();
      if (qtd_sensors == 6){vec_fsr4.clear();      vec_fsr5.clear();      vec_fsr6.clear();}


      // for (int ii=0;ii<10;ii++){
      //   udp.broadcast("got_max");
      //   delay(10);
      // }
      udp.broadcast("got_max");
      udp.broadcast("got_max");
      
      // SEND AND RECEIVE CONFIRMATION.
      confirm_message = " ";
      while(true){        
        //getSerialmsg();
        getWifimsg();
        if (confirm_message == "got_it"){ 
          //Serial.println("First Got it message received!");  
          //delay(50);
          //Serial.println("got_it");       
          //udp.broadcast("got_it");
          break;
        }       
      }

    }

    //================================================== SERIAL =============================================================    
    else if (tp_check == "serial"){    

      // I - Notify that the communication is via serial
      confirm_message = " ";
      while(true){
        Serial.println("serial");
        delay(50);
        if (Serial.available() > 0) {
          confirm_message = Serial.readString();
          
          if (confirm_message == "got_it"){
            //Serial.println("First Got it message received!"); 
            Serial.println("got_it");  
            break;
          }        
        }

        // =================================== Check if the setup button was pressed ===========================
        if((digitalRead(buttonPin))){
          type_protocol = "not configured";
          const char* tp_name = "type_protocol";  
          save_variable_jsonfile(tp_name, type_protocol);
          setup_type_of_communication();        
        } 
        // ======================================================================================================
      }    


      // II - Get the MINIMUM value of each FSR sensors
      // ===========================> Wait the confirmation in GUI to start the reading
      confirm_message = " ";
      while(true){      
        //Serial.println("getting_minimum");
        getSerialmsg();
        if (confirm_message == "got_it"){   
          //Serial.println("Second Got it message received!"); 
          delay(50);   
          Serial.println("got_it");    
          break;
        }   

        // =================================== Check if the setup button was pressed ===========================
        if((digitalRead(buttonPin))){
          type_protocol = "not configured";
          const char* tp_name = "type_protocol";  
          save_variable_jsonfile(tp_name, type_protocol);
          setup_type_of_communication();        
        } 
        // ======================================================================================================
      }

      // ===========================> Start to read during the calibration time defined
      startTime = millis();
      while (millis() - startTime < 1000*calibration_time) {  
        Serial.println("calibrating...");
        delay(50);        
        vec_fsr1.push_back(analogRead(sensor1));   vec_fsr2.push_back(analogRead(sensor2));   vec_fsr3.push_back(analogRead(sensor3));
        if (qtd_sensors == 6){
          vec_fsr4.push_back(analogRead(sensor4));   vec_fsr5.push_back(analogRead(sensor5));   vec_fsr6.push_back(analogRead(sensor6)); 
        }
      }

      for (int ii=0;ii<50;ii++){
        Serial.println("Calibration finished");
      }  
      
      // Compute the Vector Mean
      sum = std::accumulate(vec_fsr1.begin(), vec_fsr1.end(), 0.0);      fsr1_min = sum / vec_fsr1.size();
      sum = std::accumulate(vec_fsr2.begin(), vec_fsr2.end(), 0.0);      fsr2_min = sum / vec_fsr2.size();
      sum = std::accumulate(vec_fsr3.begin(), vec_fsr3.end(), 0.0);      fsr3_min = sum / vec_fsr3.size();
      if (qtd_sensors == 6){
        sum = std::accumulate(vec_fsr4.begin(), vec_fsr4.end(), 0.0);      fsr4_min = sum / vec_fsr4.size();
        sum = std::accumulate(vec_fsr5.begin(), vec_fsr5.end(), 0.0);      fsr5_min = sum / vec_fsr5.size();
        sum = std::accumulate(vec_fsr6.begin(), vec_fsr6.end(), 0.0);      fsr6_min = sum / vec_fsr6.size();
      }
      
      Serial.println("Clearing the vectors...");      
      // Clear the Vector to use them to maximum as well.
      vec_fsr1.clear();      vec_fsr2.clear();      vec_fsr3.clear();
      if (qtd_sensors == 6){vec_fsr4.clear();      vec_fsr5.clear();      vec_fsr6.clear();}


      // for (int ii=0;ii<3;ii++){
      //   Serial.println("got_min");
      // } 
      
      Serial.println("got_min");
      delay(50);
      // SEND AND RECEIVE CONFIRMATION.
      confirm_message = " ";
      while(true){     
        getSerialmsg();
        //delay(50);
        if (confirm_message == "got_it"){ 
          //Serial.println("First Got it message received!");   
          delay(50); 
          Serial.println("got_it");     
          break;
        }       
      } 

      // III - Get the MAXIMUM value of each FSR sensors
      startTime = millis();
      while (millis() - startTime < 1000*calibration_time) {  
        Serial.println("calibrating...");
        delay(50); 
        vec_fsr1.push_back(analogRead(sensor1));   vec_fsr2.push_back(analogRead(sensor2));   vec_fsr3.push_back(analogRead(sensor3));
        if (qtd_sensors == 6){
          vec_fsr4.push_back(analogRead(sensor4));   vec_fsr5.push_back(analogRead(sensor5));   vec_fsr6.push_back(analogRead(sensor6));
        }
      }

      for (int ii=0;ii<50;ii++){
        Serial.println("Calibration finished");
      }  

      // Compute the Vector Mean
      sum = std::accumulate(vec_fsr1.begin(), vec_fsr1.end(), 0.0);      fsr1_max = sum / vec_fsr1.size();
      sum = std::accumulate(vec_fsr2.begin(), vec_fsr2.end(), 0.0);      fsr2_max = sum / vec_fsr2.size();
      sum = std::accumulate(vec_fsr3.begin(), vec_fsr3.end(), 0.0);      fsr3_max = sum / vec_fsr3.size();
      if (qtd_sensors == 6){
        sum = std::accumulate(vec_fsr4.begin(), vec_fsr4.end(), 0.0);      fsr4_max = sum / vec_fsr4.size();
        sum = std::accumulate(vec_fsr5.begin(), vec_fsr5.end(), 0.0);      fsr5_max = sum / vec_fsr5.size();
        sum = std::accumulate(vec_fsr6.begin(), vec_fsr6.end(), 0.0);      fsr6_max = sum / vec_fsr6.size();
      }

      // Clear the Vectors
      vec_fsr1.clear();      vec_fsr2.clear();      vec_fsr3.clear();
      if (qtd_sensors == 6){vec_fsr4.clear();      vec_fsr5.clear();      vec_fsr6.clear();}
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
void loop() {
  currentTime = millis();  // Get the actual time

  if (currentTime - previousTime >= interval) {
    previousTime = currentTime;  // Update the previous time

    // Call your function here
    send_data();
  }
}

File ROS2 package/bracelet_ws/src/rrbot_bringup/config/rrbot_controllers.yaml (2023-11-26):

controller_manager:
  ros__parameters:
    update_rate: 2000  # Hz

    joint_state_broadcaster:
      type: joint_state_broadcaster/JointStateBroadcaster

    forward_effort_controller:
      type: forward_command_controller/ForwardCommandController

    rrbot_pdg_controller:
      type: rrbot_pdg_controller/RRbotPDGController

    rrbot_idyn_controller:
      type: rrbot_idyn_controller/RRbotIDynController


forward_position_controller:
  ros__parameters:
    joints:
      - joint1
      - joint2
    interface_name: effort


rrbot_pdg_controller:
  ros__parameters:
    joints:
      - joint1
      - joint2
    KP: 5.0
    KD: 2.0

rrbot_idyn_controller:
  ros__parameters:
    joints:
      - joint1
      - joint2
    KP: 100.0
    KD: 50.0

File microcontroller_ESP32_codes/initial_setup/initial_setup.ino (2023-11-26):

    /////////////////////////////////////////////////////////////////
   //        BRACELET TO MEASURE THE UPPER-ARM CONTRACTION        //
  //           Author: Jesse de Oliveira Santana Alves           //
 //                 Email: jessalves2@gmail.com                 //
/////////////////////////////////////////////////////////////////


// =======================================================
// ================>  Code Description  <=================
// =======================================================

// This code has to be upload first in the new microcontroller (ESP32 used in this project),
// in order to set up in a - json file - initial values of the variables: 

// const char* type_protocol;
// const char* wifi_status;
// const char* ssid_json;
// const char* password_json; 

// This is necessary, because the microcontroller main code save the wifi and protocl information,
// in order to avoid wirte down the ssid and password wifi every time to use the bracelet.
// Therefore, some variables is save into a board memory.

// =======================================================
// ====================>  Libraries  <====================
// =======================================================
#include <FS.h>
#include <SPIFFS.h>
#include <ArduinoJson.h>

// =======================================================
// ====================>  Variables  <====================
// =======================================================
const char* type_protocol;
const char* ssid_json;
const char* password_json; 

void setup() {  
  Serial.begin(115200);
  
  // Initialize SPIFFS
  if (!SPIFFS.begin(true)) {
    Serial.println("An error occurred while mounting SPIFFS");
    return;
  }

  // Create a JSON object
  StaticJsonDocument<200> doc;

  // Set variables in the JSON object
  doc["type_protocol"] = "not configured";
  doc["ssid_json"] = "none";
  doc["password_json"] = "none";

// ============================================= Saving the variables from json file
  // Open the file in write mode
  File file = SPIFFS.open("/protocol_info.json", "w");
  if (!file) {
    Serial.println("Failed to open file for writing");
    return;
  }

  // Serialize the JSON object to the file
  if (serializeJson(doc, file) == 0) {
    Serial.println("Failed to write to file");
  }

  // Close the file
  file.close();

  // =========================================== CHECKING IF THE VARIABLES WAS WRITTEN ==============================
    // Read the file from SPIFFS
  //File file = SPIFFS.open("/config.json", "r");
  file = SPIFFS.open("/protocol_info.json", "r");
  if (!file) {
    Serial.println("Failed to open file for reading");
    return;
  }

  // Parse the JSON file and store the data in the JSON object
  DeserializationError error = deserializeJson(doc, file);
  if (error) {
    Serial.println("Failed to parse file");
  }

  // ============================================= Reading the variables from json file
  type_protocol = doc["type_protocol"];
  ssid_json = doc["ssid_json"];
  password_json = doc["password_json"]; 

  // Print Variable to test if the reading was with success
  Serial.println("Check the Writing Variables:");
  Serial.println(type_protocol);
  Serial.println(ssid_json);
  Serial.println(password_json);

  // Close the file
  file.close();

  Serial.println(" ");
  Serial.println("The Initial Setup was done with success!");
}

void loop() {
}

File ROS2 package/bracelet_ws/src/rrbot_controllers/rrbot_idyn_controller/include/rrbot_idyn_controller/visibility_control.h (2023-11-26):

// Copyright 2023, ICube Laboratory, University of Strasbourg
//
// Licensed under the Apache License, Version 2.0 (the "License");
// you may not use this file except in compliance with the License.
// You may obtain a copy of the License at
//
//     http://www.apache.org/licenses/LICENSE-2.0
//
// Unless required by applicable law or agreed to in writing, software
// distributed under the License is distributed on an "AS IS" BASIS,
// WITHOUT WARRANTIES OR CONDITIONS OF ANY KIND, either express or implied.
// See the License for the specific language governing permissions and
// limitations under the License.

#ifndef RRBOT_IDYN_CONTROLLER__VISIBILITY_CONTROL_H_
#define RRBOT_IDYN_CONTROLLER__VISIBILITY_CONTROL_H_

// This logic was borrowed (then namespaced) from the examples on the gcc wiki:
//     https://gcc.gnu.org/wiki/Visibility

#if defined _WIN32 || defined __CYGWIN__
#ifdef __GNUC__
#define RRBOT_IDYN_CONTROLLER_EXPORT __attribute__((dllexport))
#define RRBOT_IDYN_CONTROLLER_IMPORT __attribute__((dllimport))
#else
#define RRBOT_IDYN_CONTROLLER_EXPORT __declspec(dllexport)
#define RRBOT_IDYN_CONTROLLER_IMPORT __declspec(dllimport)
#endif
#ifdef RRBOT_IDYN_CONTROLLER_BUILDING_DLL
#define RRBOT_IDYN_CONTROLLER_PUBLIC RRBOT_IDYN_CONTROLLER_EXPORT
#else
#define RRBOT_IDYN_CONTROLLER_PUBLIC RRBOT_IDYN_CONTROLLER_IMPORT
#endif
#define RRBOT_IDYN_CONTROLLER_PUBLIC_TYPE RRBOT_IDYN_CONTROLLER_PUBLIC
#define RRBOT_IDYN_CONTROLLER_LOCAL
#else
#define RRBOT_IDYN_CONTROLLER_EXPORT __attribute__((visibility("default")))
#define RRBOT_IDYN_CONTROLLER_IMPORT
#if __GNUC__ >= 4
#define RRBOT_IDYN_CONTROLLER_PUBLIC __attribute__((visibility("default")))
#define RRBOT_IDYN_CONTROLLER_LOCAL __attribute__((visibility("hidden")))
#else
#define RRBOT_IDYN_CONTROLLER_PUBLIC
#define RRBOT_IDYN_CONTROLLER_LOCAL
#endif
#define RRBOT_IDYN_CONTROLLER_PUBLIC_TYPE
#endif

#endif  // RRBOT_IDYN_CONTROLLER__VISIBILITY_CONTROL_H_
